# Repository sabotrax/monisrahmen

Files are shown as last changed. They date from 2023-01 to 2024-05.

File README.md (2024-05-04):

# monisrahmen

A digital picture frame you can send emails to.

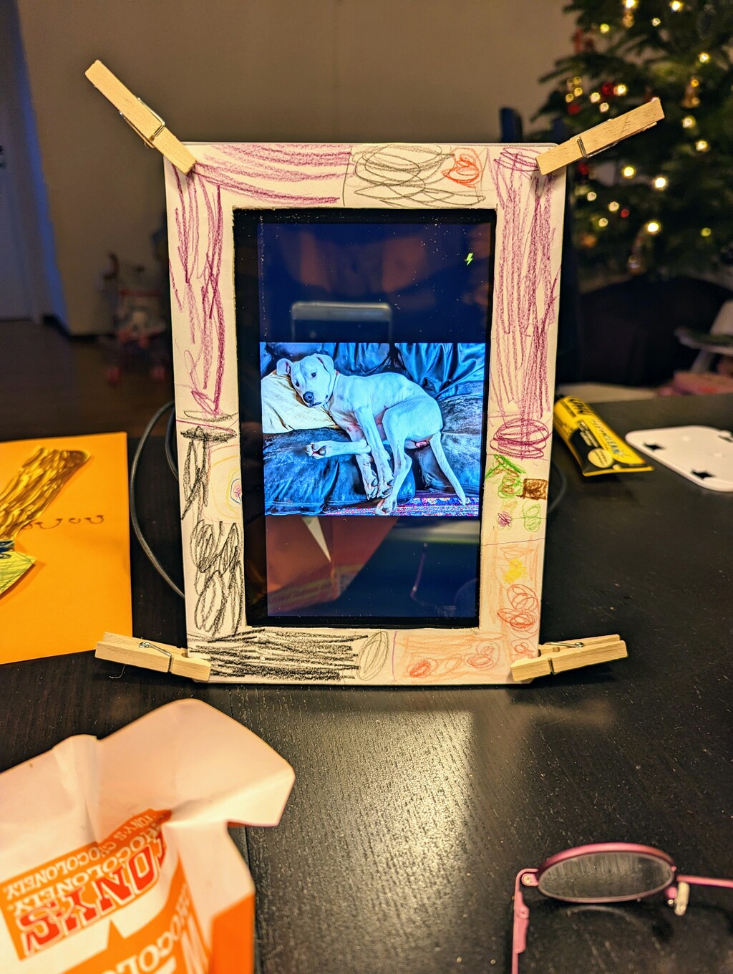
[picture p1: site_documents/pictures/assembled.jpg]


## Description

Send pictures as email attachments or put them on a network share.
They will be displayed in a random loop. 

The frame is 3D printed.  
Some light soldering may be required.

## Features

* Send one or more pictures as email attachments.
* Add more pictures by putting them on a network share.
* Duplicate files and non-image formats will be ignored.
* Screen blanking is controlled by a motion sensor.
* Off-hours can be enabled, so the screen stays off after blanking.
* A splash screen is showing device information.
* Most options are configurable.

### Remark

There's a redesigned version of the frame.  
Files with the naming scheme *frame2_* are referring to it.  
They're located in [site_documents/](site_documents/).  
A larger printer is required also.  
The software installation largely stays the same.

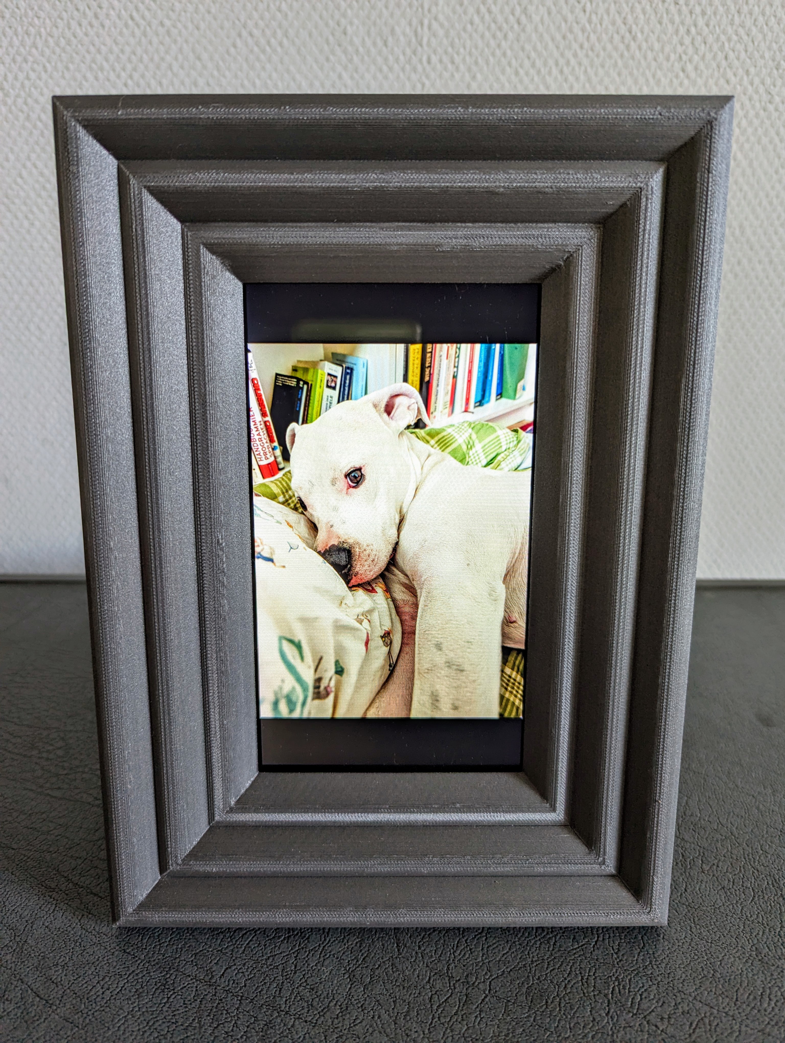
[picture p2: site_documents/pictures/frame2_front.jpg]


### Bill of materials

* 1 Raspberry Pi 2  
  The Raspberry 2 is sufficient for this project and can be found for relatively cheap in late 2022.
* 1 USB WLAN adapter like Edimax or TP-Link brand
* 1 WaveShare model 7" IPS/QLED Integrated Display, 1024x600, 70H-1024600
* 1 RCWL-0516 doppler radar microwave motion sensor module
* 1 HDMI cable of 30 cm length
* 8 M2.5 screws, nuts and standoffs  
  Plastic is fine.
* 1 USB-A to Micro USB-B cable
* 1 USB-A to USB-C cable
* 1 USB wall charger  
  The power draw of the display is about 350 mA. 100 mA when blanked.
* 6 square head female-to-female DuPont cables
* 1 4x1 male pin-headers
* Small cable ties

### Tools

* Soldering equipment
* Hot glue gun

### 3D printing

The STL files are located in ``site_documents/designs/``.  
Frame and stand have been printed in PETG with 15 % infill and supports, but PLA will also work.

### Hardware setup

* See [ASSEMBLY](site_documents/ASSEMBLY.md).

### Installing

* Install Pi OS Lite 32-bit using the Raspberry Pi Imager.  
  You can set up the host name, user account, SSH and Wifi in the options of the Imager.
  You should then be able to ssh into your Raspberry.

* Install dependencies:
    ```
    sudo apt-get install fbi fonts-dejavu-core git incron python3 python3-pip python3-venv samba
    ```

    If using DietPi instead of Pi OS add also:
    ```
    sudo apt-get install libopenjp2-7 libxcb1
    ```

* Download the software:
    ```
    git clone https://github.com/sabotrax/monisrahmen.git
    ```

* Create the virtual environment for Python and install the required modules:
    ```
    cd monisrahmen
    python3 -m venv .
    source bin/activate
    pip3 install -r requirements.txt
    echo "source ~/monisrahmen/bin/activate" >> ~/.bashrc
    ```

* Create ``.env`` as the configuration file:
    ```
    # installation directory
    PROJECT_PATH=/home/schommer/monisrahmen
    # email account settings
    EMAIL_USER=IMAP_USER
    EMAIL_PASS=IMAP_PASSWORD
    EMAIL_HOST=IMAP_HOST
    EMAIL_PORT=993
    EMAIL_INBOX=Inbox
    # email subject for image processing
    EMAIL_KEYWORD=foto
    # number of emails to fetch
    FETCH_EMAIL=5
    # delete emails after retrieval
    DELETE_EMAIL=False
    # unkown sender
    UNKNOWN_SENDER=Unknown
    # image reload time (seconds)
    RELOAD_IMAGE=120
    # image transition time (milliseconds)
    BLEND_IMAGE=500
    # motion sensor (either or)
    MOTION_SENSOR=RCWL-0516
    #MOTION_SENSOR=HLK-LD2410C # redesigned version
    # motion sensor timeout for screen blanking (seconds)
    DISPLAY_TIMEOUT=120
    # display off-hours
    # the screen stays off after blanking during this period
    # leave empty if not using
    START_DISPLAY_OFF=23:00
    END_DISPLAY_OFF=07:00
    # monitoring is not implemented yet
    # leave empty if not using
    START_MONITORING=
    END_MONITORING=
    # network device
    NETWORK_DEVICE=wlan0
    # network error message
    NETWORK_ERROR="Network error!"
    # splash image font
    FONT_SIZE=30
    # screen resolution
    SCREEN_WIDTH=1024
    SCREEN_HEIGHT=600
    # be verbose
    DEBUG=False
    ```

* Configure the display in ``/boot/config.txt``.  
    For the WaveShare model 7" IPS/QLED 1024x600 70H-1024600:
    ```
    hdmi_group=2
    hdmi_mode=87
    hdmi_cvt=1024 600 60 6 0 0 0
    hdmi_drive=1
    ```

    Display blanking:
    ```
    #dtoverlay=vc4-kms-v3d
    hdmi_blanking=1
    ```
    Blanking an HDMI display would work only on the Pi 2 if we used the legacy graphics driver.

    Rotate the virtual console:
    ```
    display_hdmi_rotate=3
    ```
    This would also only work with the legacy driver.

* Suppress boot messages.  
    Append to the end of the line of ``/boot/cmdline.txt``:
    ```
    consoleblank=1 logo.nologo vt.global_cursor_default=0
    ```

    Add to ``/boot/config.txt``:
    ```
    avoid_warnings=1
    disable_splash=1
    ```

* Configure the Samba share.  
    Add to the end of ``/etc/samba/smb.conf``:
    ```
    [bilder]
    # change accordingly to your installation directory
    path = /home/schommer/monisrahmen/pictures/
    public = yes
    writable = yes
    comment = Bilder
    printable = no
    guest ok = yes
    ```

    Change directory rights so image files can be managed from your file manager:
    ```
    chmod 777 pictures/
    ```

* Edit the shell scripts.  
    Change the installation directories in ``sitebin/restart_fbi.sh`` and ``sitebin/startup.sh``.  
    You can now test the scripts by setting ``DEBUG=True`` in ``.env``,  
    then send an image to the email address using the keyword as the subject and  
    ```
    ./get_pics_by_mail.py
    ```
    You should find the image file in pictures/.  
    Next, add another image to the Samba share and
    ```
    ./sync_database.py
    ```
    If you ``cat user_data/db.json``, there should be two entries in the database.

* Set up Cron.  
    For your user ``crontab -e``:
    ```
    INST_DIR=/home/schommer/monisrahmen
    VENV_PYTHON=/home/schommer/monisrahmen/bin/python3
    @reboot                $VENV_PYTHON $INST_DIR/blank_screen.py
    0,15,30,45 * * * *     $VENV_PYTHON $INST_DIR/get_pics_by_mail.py
    @hourly                $VENV_PYTHON $INST_DIR/sync_database.py
    ```

    For root ``sudo crontab -e``:
    ```
    INST_DIR=/home/schommer/monisrahmen
    @reboot                $INST_DIR/sitebin/startup.sh > /dev/null 2>&1
    ```

    Adjust INST_DIR according to your installation directory.  

* Set up incron.  
    Add root to ``/etc/incron.allow``:
    ```
    echo root > /etc/incron.allow
    ```

    For root ``sudo incrontab -e``:
    ```
    /home/schommer/monisrahmen/site_run     IN_CREATE       /home/schommer/monisrahmen/sitebin/restart_fbi.sh
    ```

    Adjust the directories in the incrontab file accordingly.  
    fbi is restarted by incron after a new image attachment has been downloaded and processed.

* Optimize the system.  
    Disable logging in ``/etc/systemd/journald.conf``:
    ```
    Storage=none
    ```

    Disable unnecessary services:
    ```
    systemctl disable avahi-daemon
    systemctl stop avahi-daemon
    systemctl disable triggerhappy
    systemctl stop triggerhappy
    ```

## License

Distributed under the New BSD License, see LICENSE.txt.

## Acknowledgments

Inspiration, documentation, code snippets, etc.
* [Building a living photo frame](https://www.ofbrooklyn.com/2014/01/2/building-photo-frame-raspberry-pi-motion-detector/)
* Waveshare display [Wiki](https://www.waveshare.com/wiki/70H-1024600) 
* [RCWL-0516](https://github.com/jdesbonnet/RCWL-0516) microwave radar motion detector
* Raspberry Pi [config.txt](https://www.raspberrypi.com/documentation/computers/config_txt.html) documentation
* Crontab configuration ``man 5 crontab``
* incrontab configuraiton ``man 5 incrontab``
* Samba configuration ``man 5 smb.conf``
* fbi - Linux framebuffer image viewer ``man fbi``

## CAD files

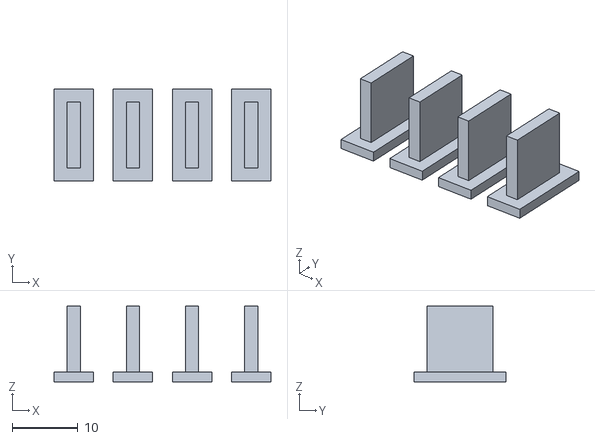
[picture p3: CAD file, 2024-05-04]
site_documents/designs/frame2_passepartout_pin.stl
33.0 x 14.0 x 11.5

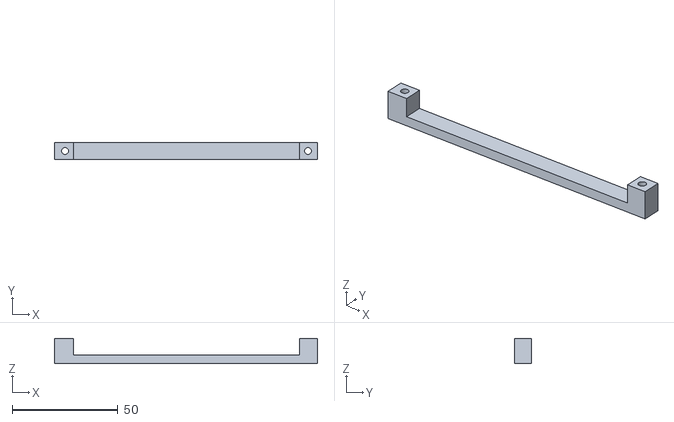
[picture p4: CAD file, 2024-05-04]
site_documents/designs/frame2_upper_bracket.stl
124.5 x 8.00 x 12.0

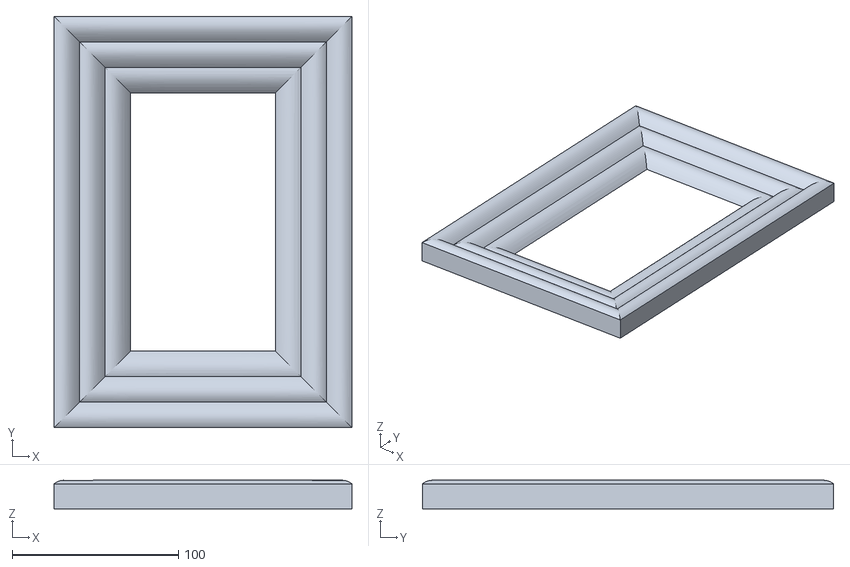
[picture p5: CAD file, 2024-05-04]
site_documents/designs/frame2_passepartout.stl
179.0 x 247.0 x 17.1

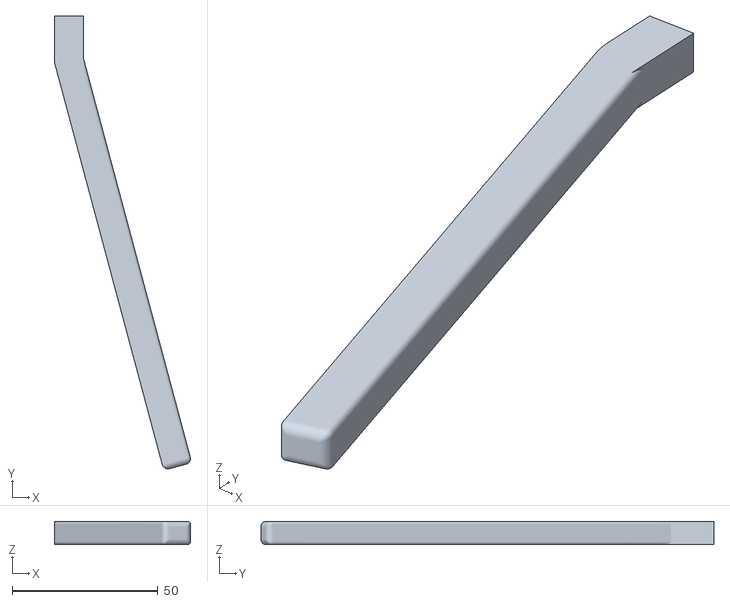
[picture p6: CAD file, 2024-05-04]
site_documents/designs/frame2_stand.stl
46.7 x 155.6 x 8.00

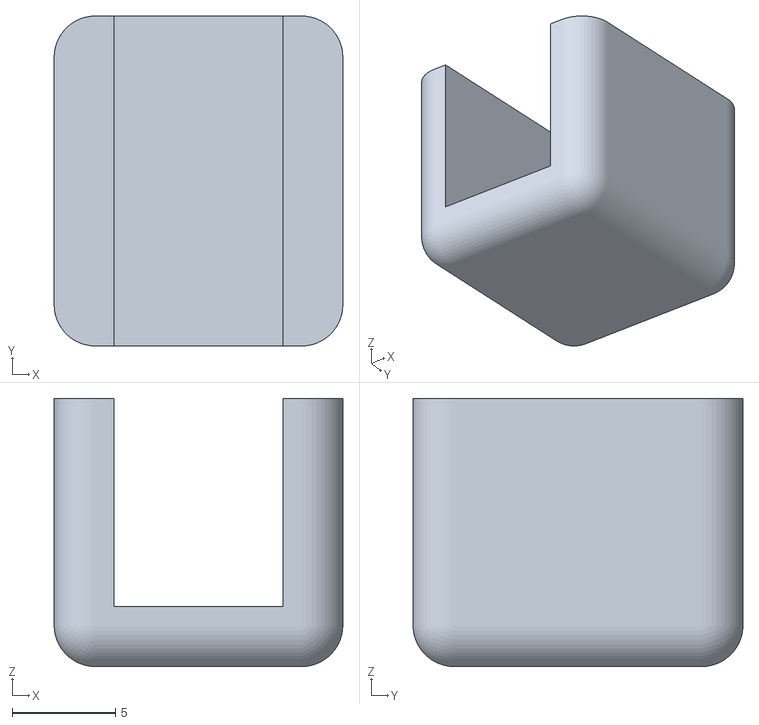
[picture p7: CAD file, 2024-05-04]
site_documents/designs/frame2_stand_mount.stl
14.0 x 16.0 x 13.0

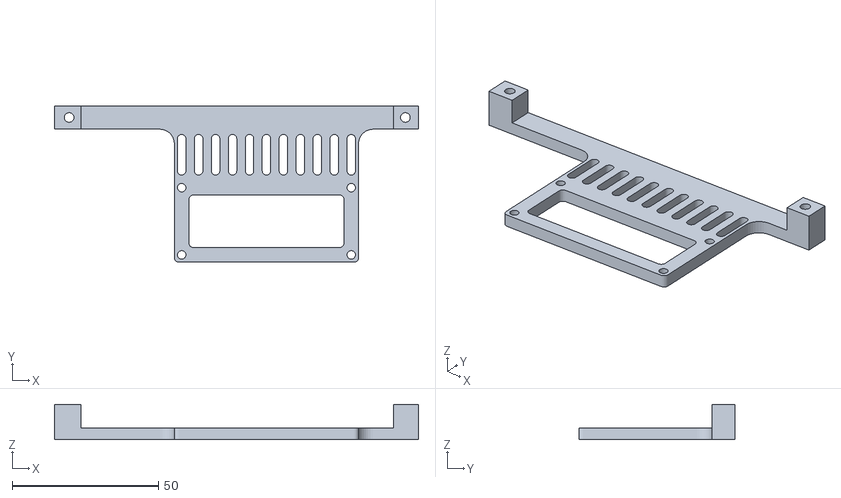
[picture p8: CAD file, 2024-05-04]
site_documents/designs/frame2_lower_bracket_pi_mount.stl
124.5 x 53.5 x 12.0

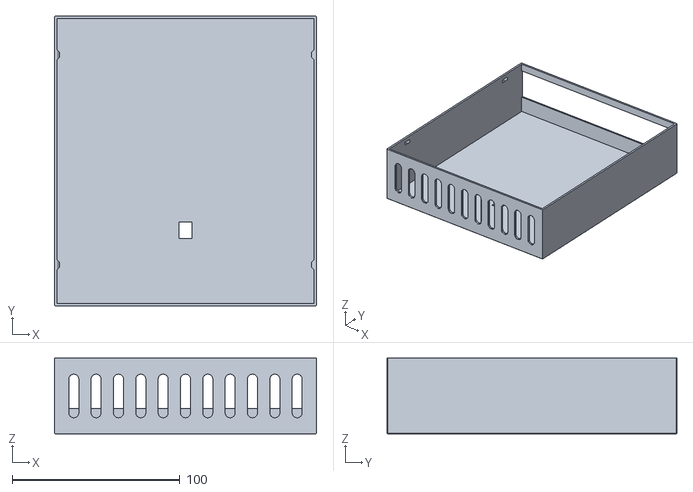
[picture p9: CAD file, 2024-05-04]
site_documents/designs/frame2_case.stl
156.0 x 172.5 x 45.0

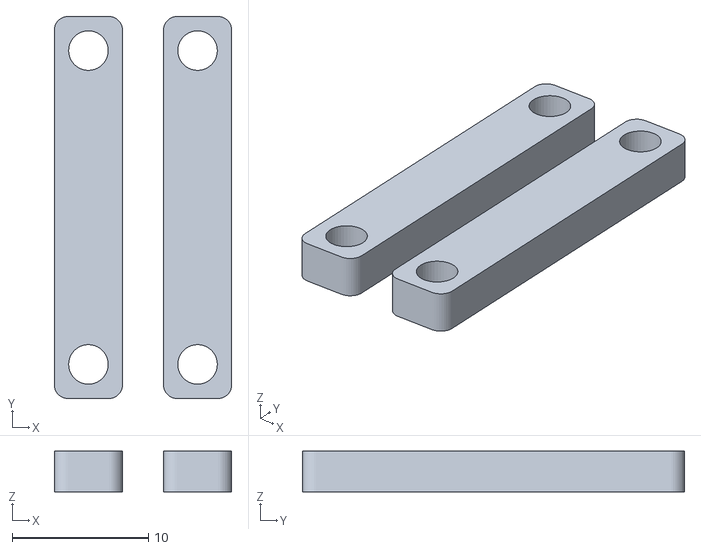
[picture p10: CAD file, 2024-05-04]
site_documents/designs/frame2_pi_spacer.stl
13.0 x 28.0 x 3.00

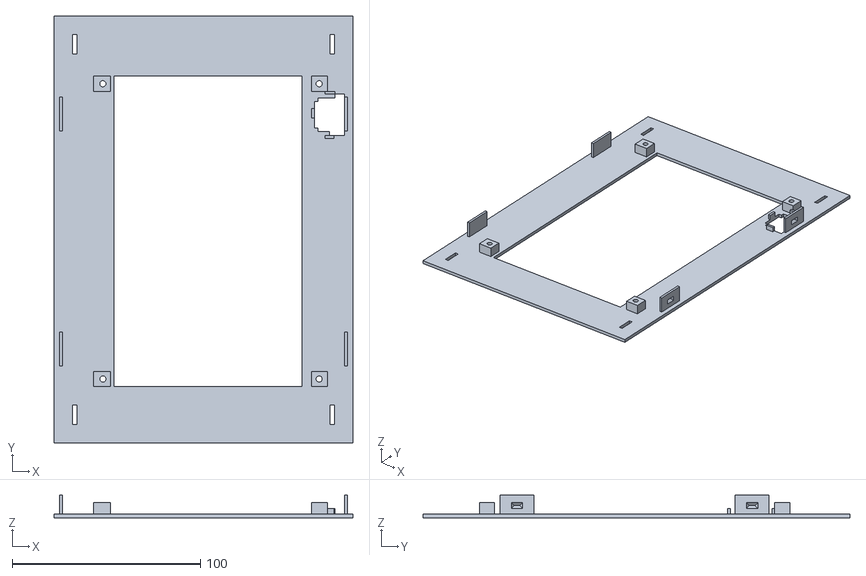
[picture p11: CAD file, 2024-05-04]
site_documents/designs/frame2_base.stl
159.0 x 227.0 x 12.0

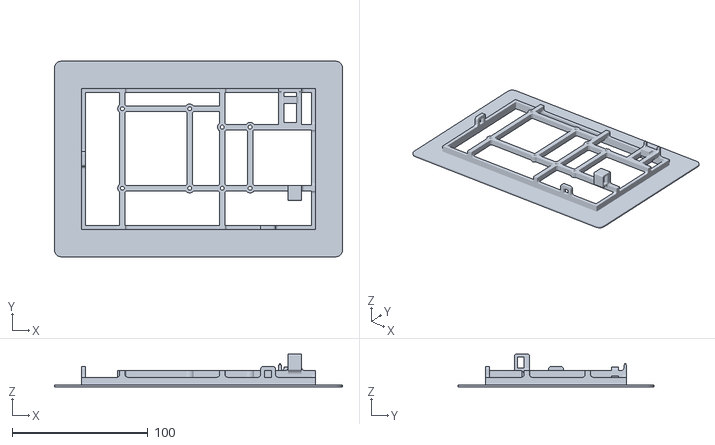
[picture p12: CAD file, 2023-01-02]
site_documents/designs/mr_frame.stl
212.0 x 144.0 x 24.0

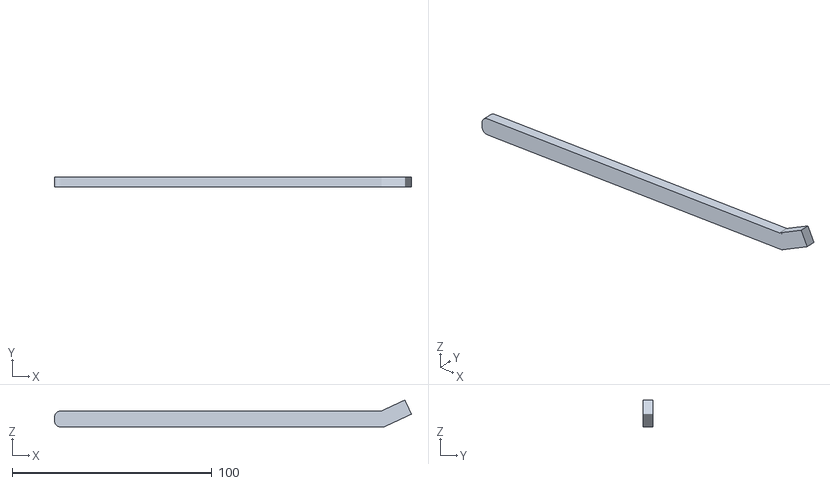
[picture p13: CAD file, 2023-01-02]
site_documents/designs/mr_stand.stl
178.6 x 5.00 x 13.5

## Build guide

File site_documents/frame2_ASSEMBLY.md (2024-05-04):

## Assembly instructions

### Overview

These instructions are for the redesigned frame.

### BOM:

* Printed parts.
* 4 x M3*18 screw and nut.
* 4 x M25*12 screw and nut.
* 3 x Jumper wire female-to-female 20 cm.
* 1 x HDMI cable mini HDMI male to HDMI male 30 cm.
* 1 x USB cable micro male to micro male.
* 1 x USB cable A to micro male.
* 1 x Display Waveshare 7inch QLED 1024×600 (Touch is not used atm, so this is a waste of money. Go for the non-touch version if available.)
* 1 x Raspberry Pi Zero 2.
* 1 x Sensor HLK-LD2410C Human Presence Motion Module.

### Step 1

* Use pictures/frame2_board.jpg as a reference.
* Mount the Pi Zero to the lower bracket using 4 x M25 screws fitting the spacers between Pi and bracket.

### Step 2

* Insert 4 x M3 screws into the base from underneath.
* Mount the display onto the base via the screws with the HDMI port facing down and away from the sensor mount.

### Step 3

* Mount the lower and upper brackets onto the base and fix them with 4 x M3 nuts.

### Step 4

* Connect 3 jumper wires to the pins of the sensor VCC, GND and OUT.
* Connect the wires to the Pi VCC to Pin 2 (5V), GND to Pin 6 (GND) and OUT to Pin 11 (GPIO17).
* Secure the sensor to the base with a drop of super glue (optional).

### Step 5

* Use frame2_back.jpg as a reference. 
* Glue the mount of the stand to the case so that it sits above the opening in the back.

### Step 6

* Clip the case onto the snap fits of the base with the groves in the case facing up.
* Connect the display to the Pi using the USB and HDMI cables fitting the cables through the culvert of the case. Use the non-touch micro USB port of the display.
* Connect the USB A cable to the remaining micro USB port of the Pi to power the frame.

### Step 7

* Put the base on the passepartout and fix it with the retaining pins. You might have to sand down the pins somewhat.
* Fit the stand into the mount on the back of the case. You might have to sand down the insert part of the stand somewhat.

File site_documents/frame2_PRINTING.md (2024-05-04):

## 3D printing instructions

### Overview

These instructions are for the redesigned frame.

All parts can be printed in PLA with default infill (15% grid in OrcaSlicer for example).

#### With support

* base, lower_bracket_pi_mount, upper_bracket.
* case: add/paint additional manual support under the wide bridge (upper of the culvert).

#### Without support

* passepartout, passpartout_pins, pi_spacer, stand, stand_mount.

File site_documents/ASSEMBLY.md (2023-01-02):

## Assembly instructions

### Overview

Parts of the mounting frame:
* The base plate for the sensor board in the top left.
* The slot for the frame stand in the top right.
* The mounting holes for the daughter board of the display in the upper mid.
* The mounting holes for the Raspberry Pi in the lower half.
* Two strain reliefs in the upper right and bottom mid.

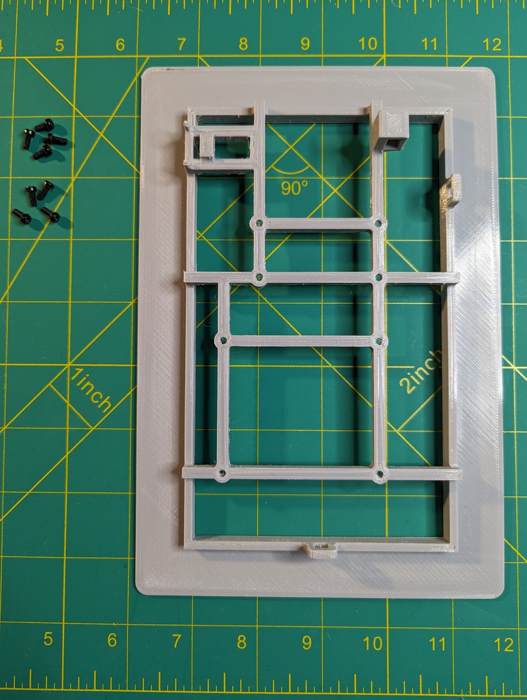
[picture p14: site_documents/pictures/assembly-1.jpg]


### Step 1

Push 8 M2.5 screws through the mounting holes from the bottom side up.

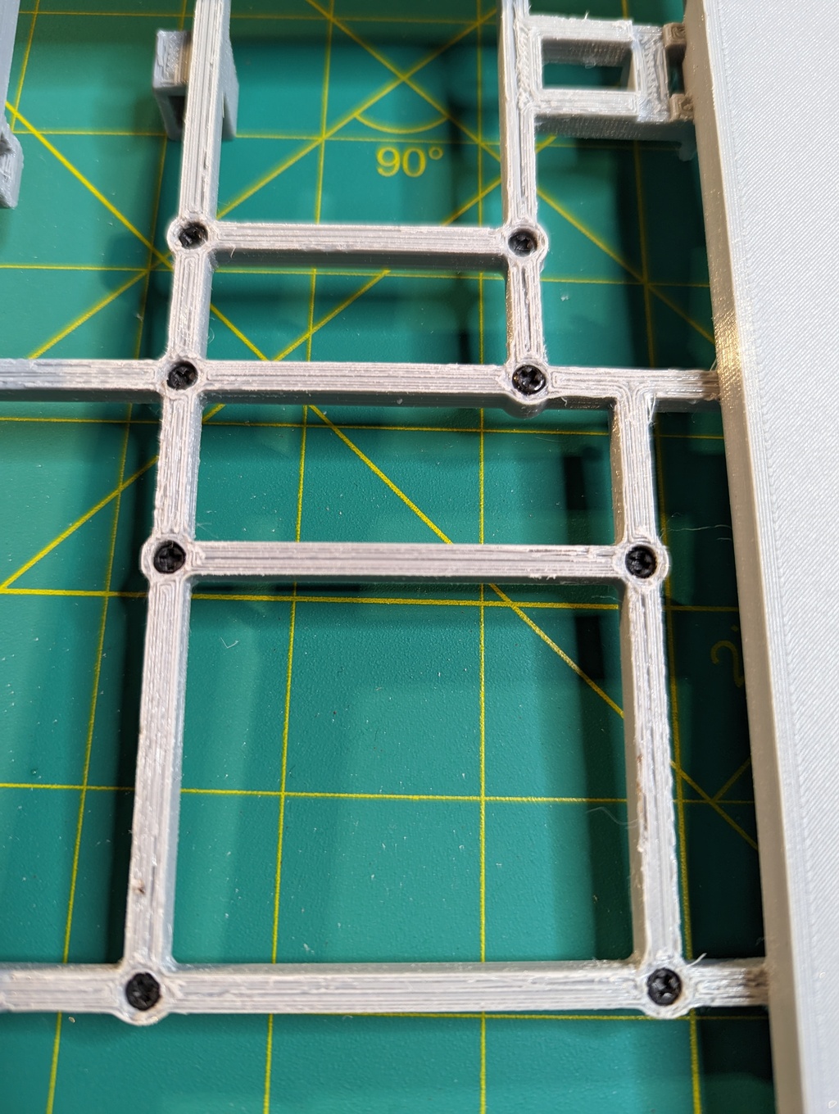
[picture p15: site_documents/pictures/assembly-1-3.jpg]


The outcome should look like this:

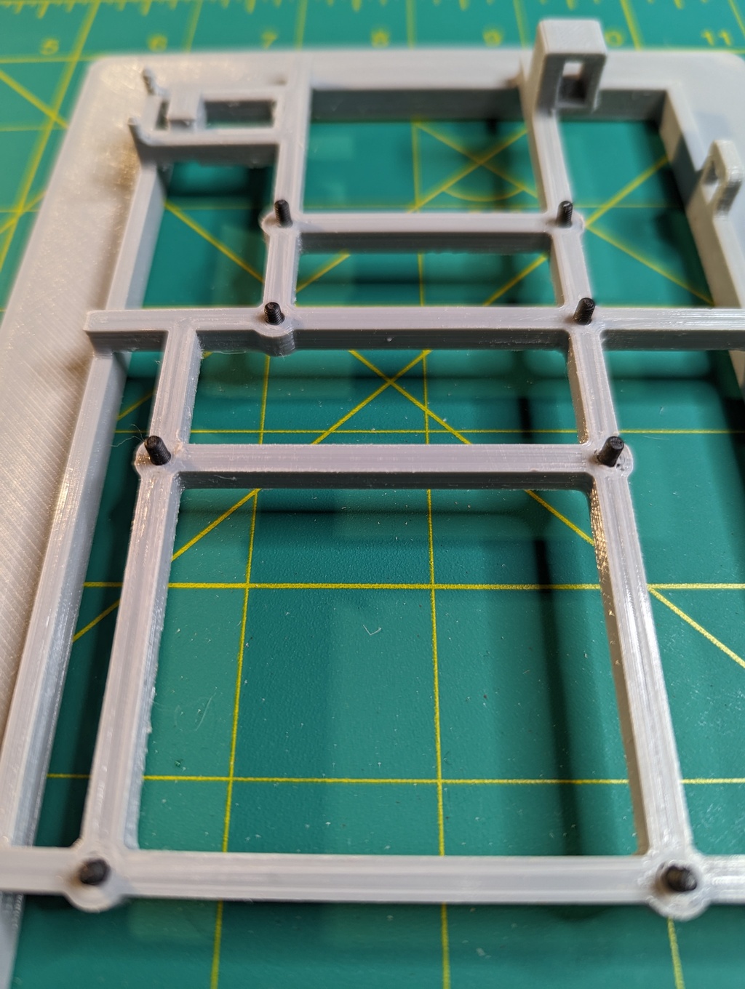
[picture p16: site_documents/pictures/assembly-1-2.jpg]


### Step 2

Screw 8 M2.5 standoffs onto the screws.

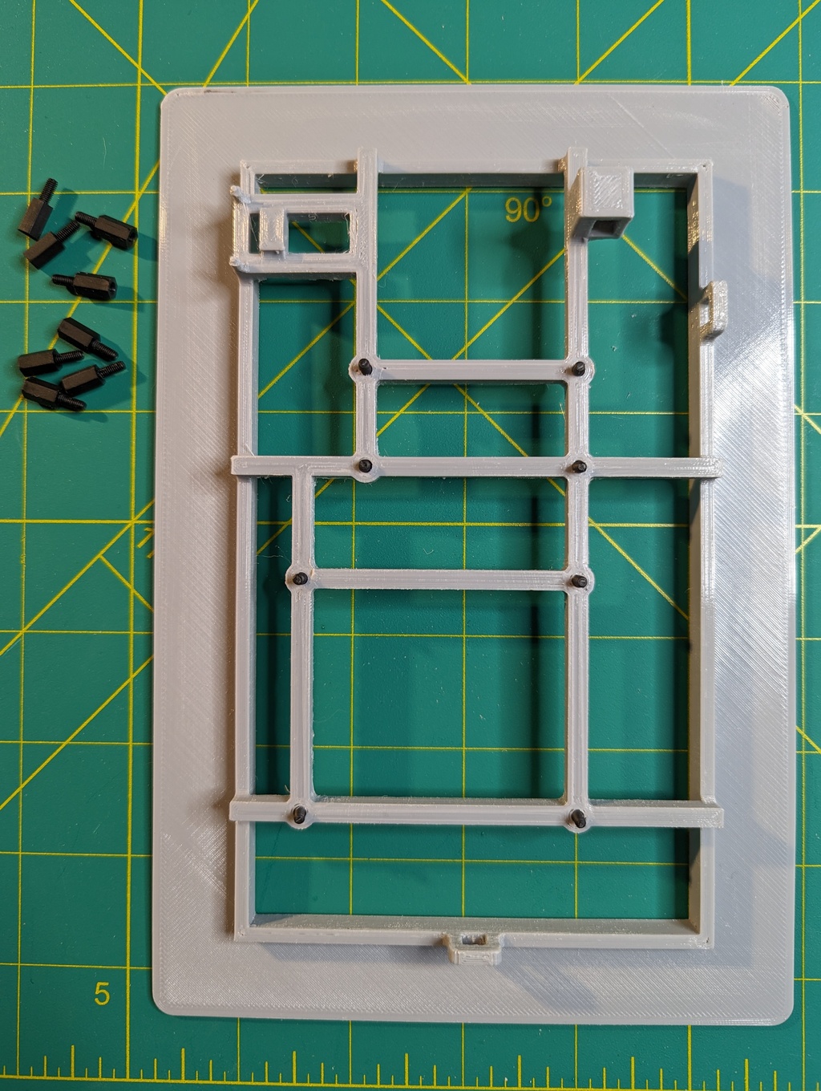
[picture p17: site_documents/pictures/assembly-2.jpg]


The outcome should look like this:

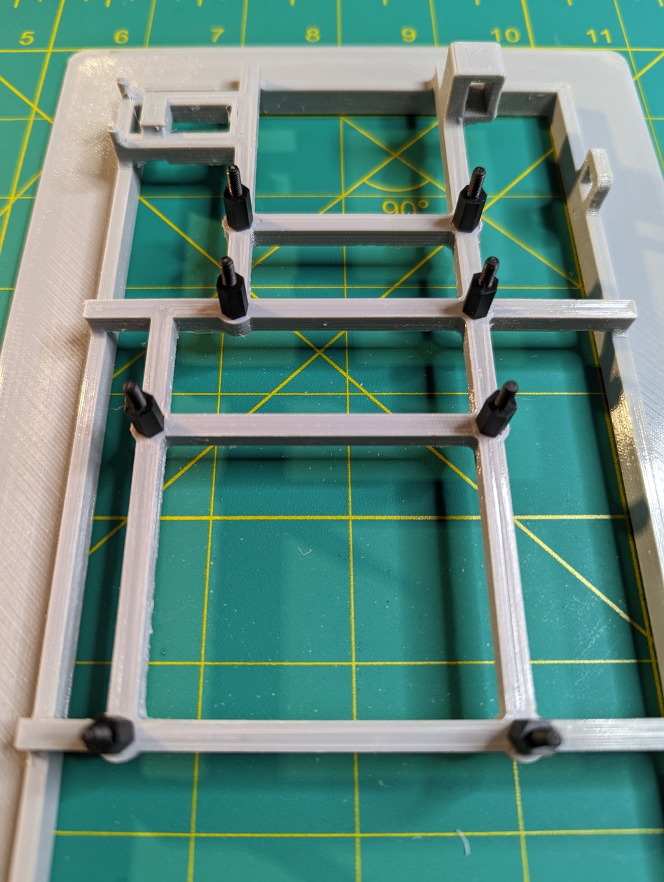
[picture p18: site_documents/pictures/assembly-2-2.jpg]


### Step 3

Solder the 4x1 pin-header to the back side of the sensor board.  
The sensor's actual antenna is facing down.

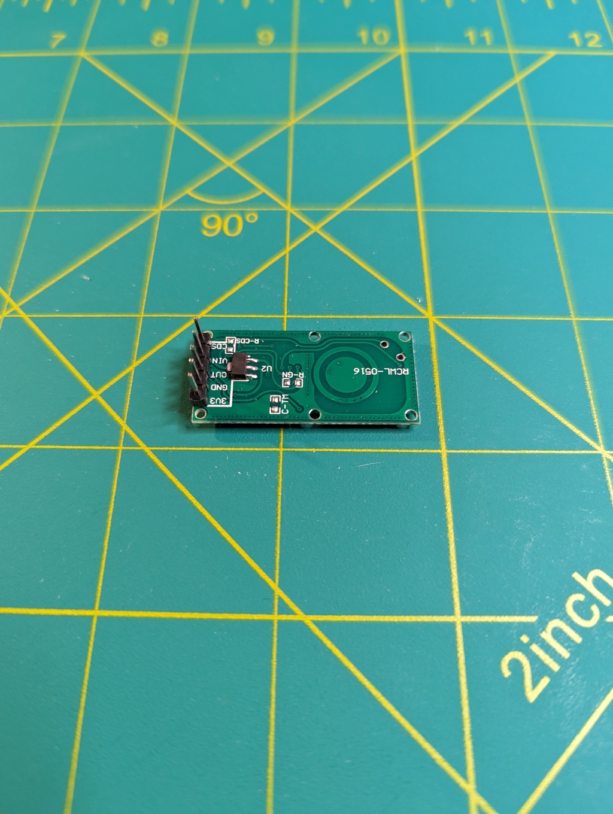
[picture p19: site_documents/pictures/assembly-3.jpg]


### Step 4

Connect the boards (board pin numbering, not BCM) using 6 DuPont cables.
* Raspberry Pi to radar sensor board:  
  2 - VIN  
  6 - GND  
  11 - OUT  
  13 - CDS  
* Raspberry Pi to HDMI board:   
  12 - PWM  
  14 - GND  

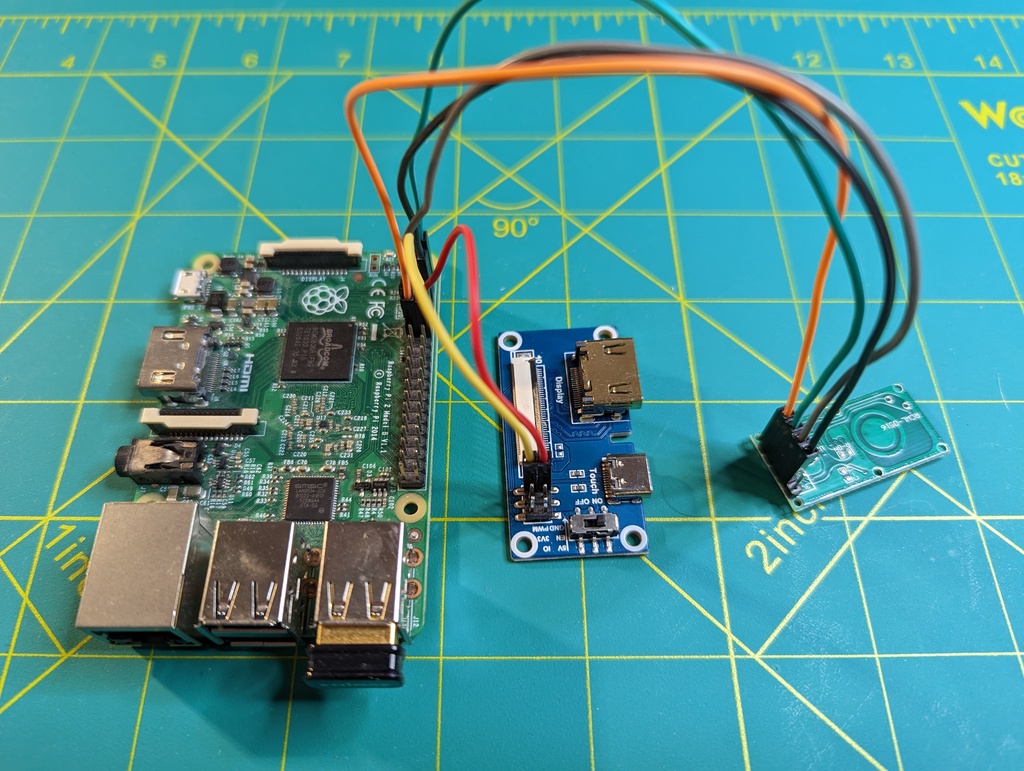
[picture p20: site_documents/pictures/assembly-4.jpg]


Mount the Raspberry Pi and sensor board onto the standoffs and tighten them down with 8 M2.5 nuts.

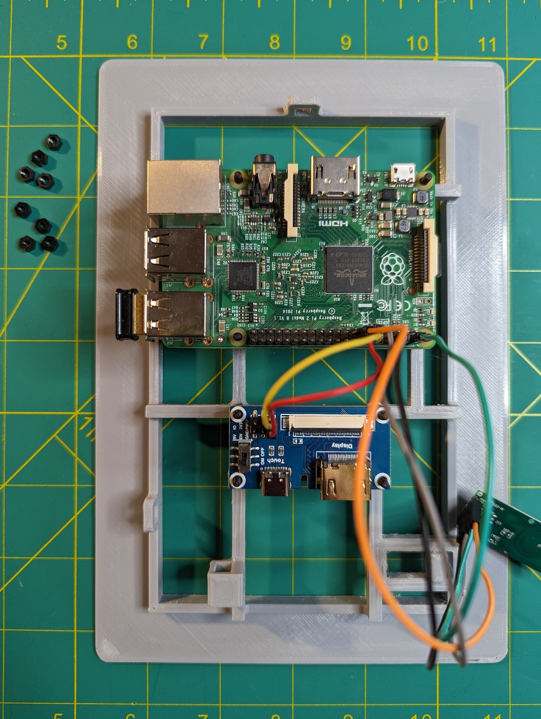
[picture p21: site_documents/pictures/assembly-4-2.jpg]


The outcome should look like this:

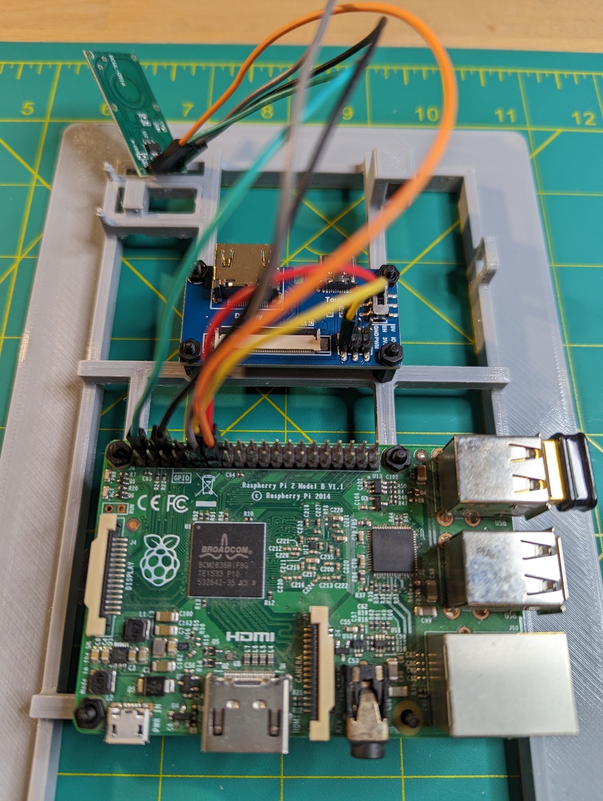
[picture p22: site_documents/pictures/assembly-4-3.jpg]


### Step 5

Place the sensor board onto the two tiny standoffs of the frame using the central mounting holes.  
Tie the board to the base plate using a cable tie. There's a gap for the tie on the underside of the frame.

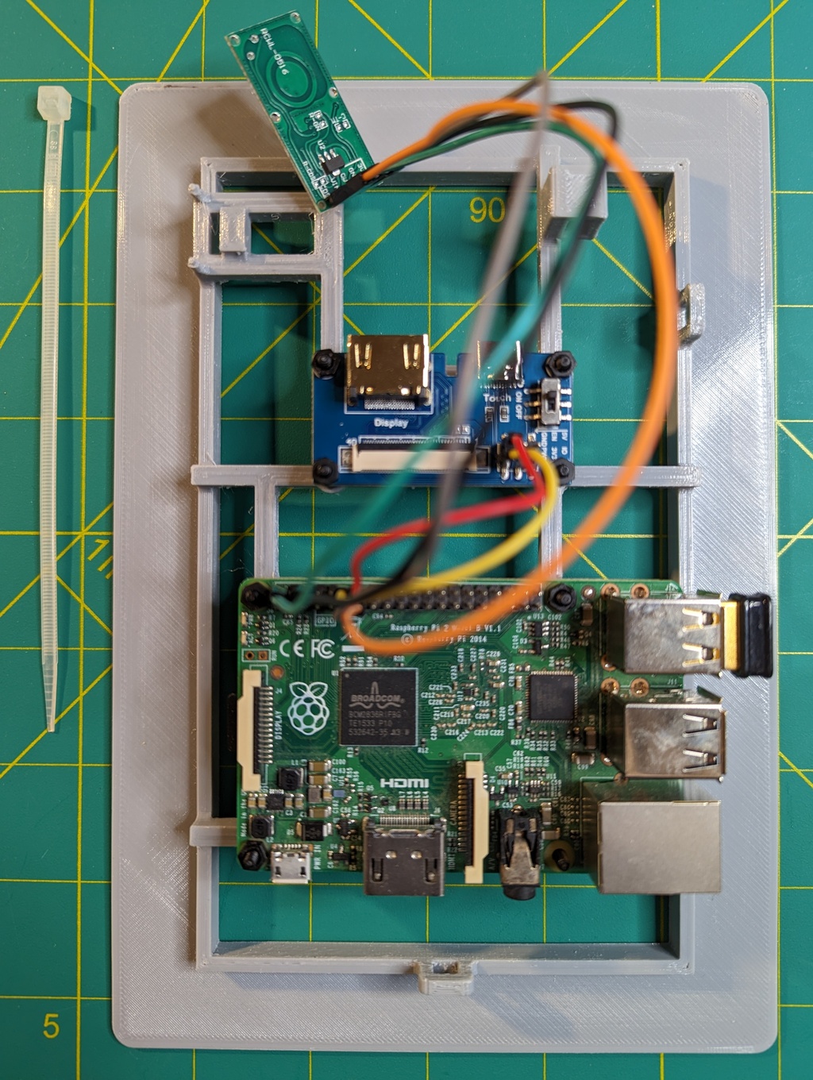
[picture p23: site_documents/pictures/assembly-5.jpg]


The outcome should look like this:

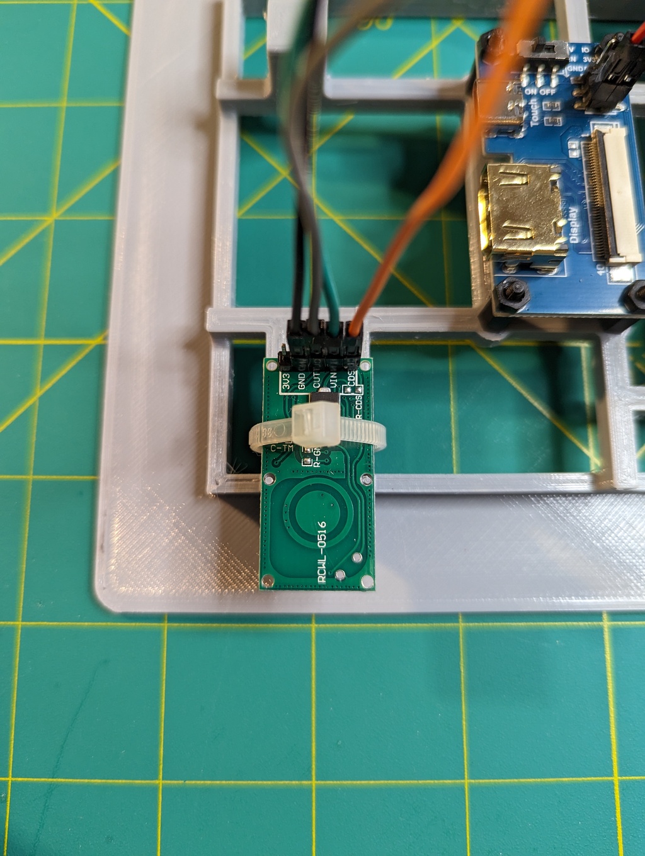
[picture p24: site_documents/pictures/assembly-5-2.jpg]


### Step 6

Connect the HDMI ports of the Raspberry Pi and the daughter board of the display with the HDMI cable.

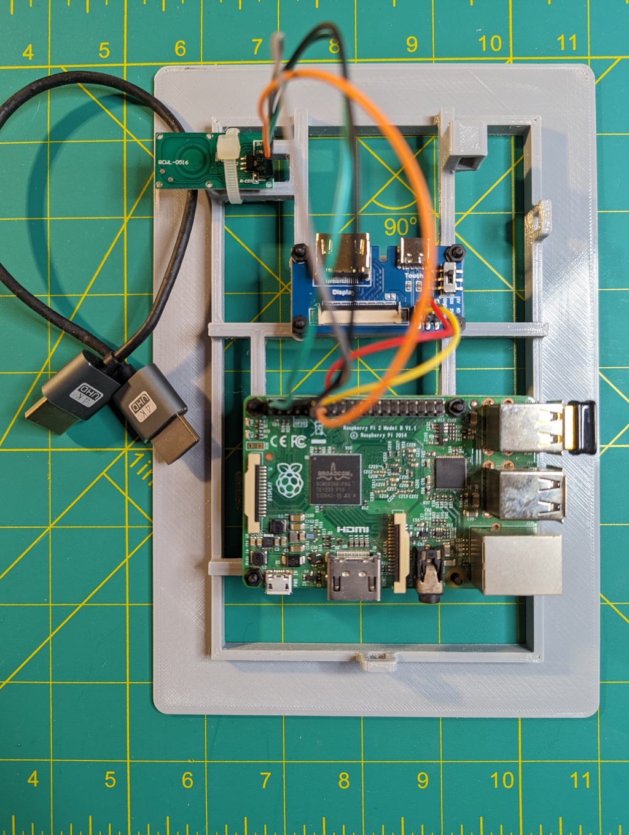
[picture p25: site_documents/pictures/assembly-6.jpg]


The outcome should look like this:

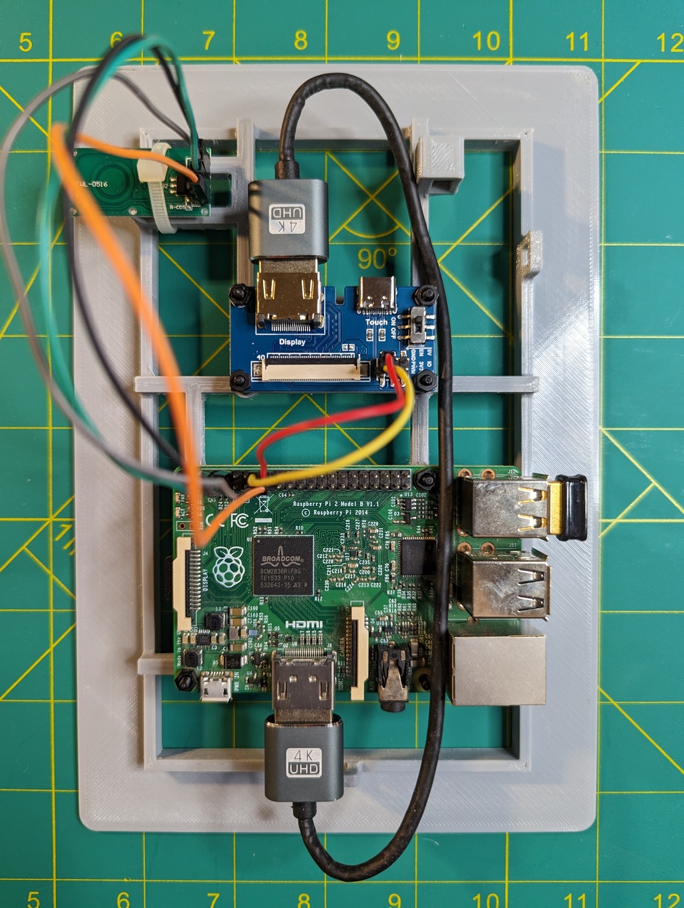
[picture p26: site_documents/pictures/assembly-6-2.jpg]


### Step 7

Using the USB cable, connect the USB-C port of the HDMI board to a USB-A port of the Raspberry Pi.  
Secure it to the frame using the strain relief. You might want to use a shorter cable than I did.

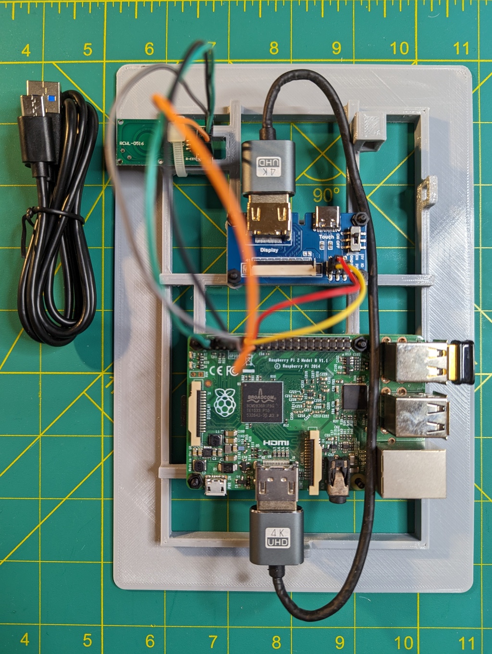
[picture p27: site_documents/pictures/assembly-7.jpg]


The outcome should look like this:

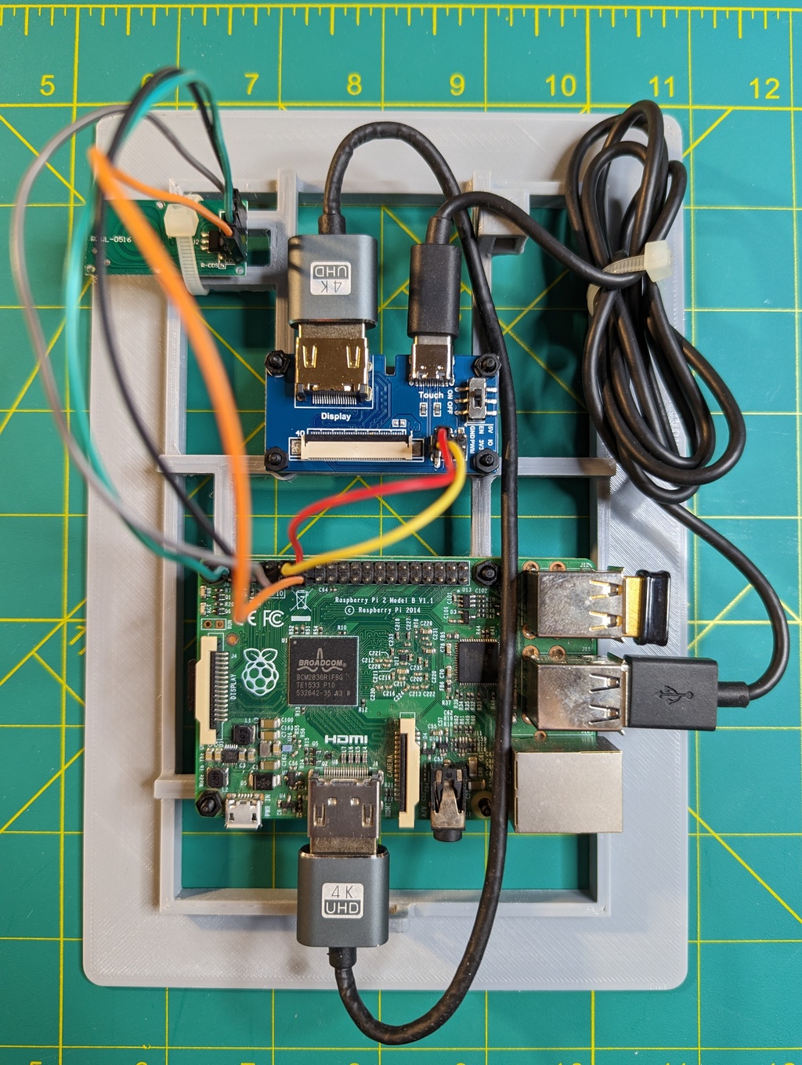
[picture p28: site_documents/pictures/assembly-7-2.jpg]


### Step 8

Connect the HDMI-FPC cable to the display with the lettering on the cable facing towards you.  
These cables are susceptible to breaking, so you might want to consider a tutorial on Youtube.

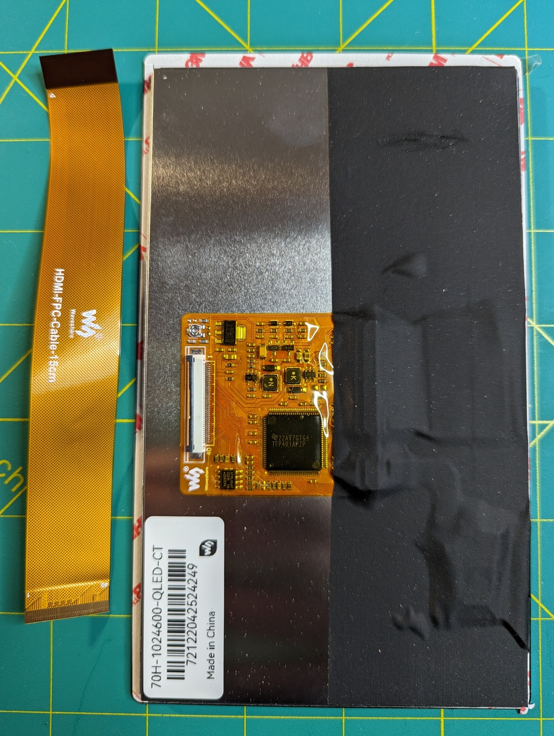
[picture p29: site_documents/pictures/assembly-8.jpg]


Put the frame over the display passing the FPC table up through the frame.

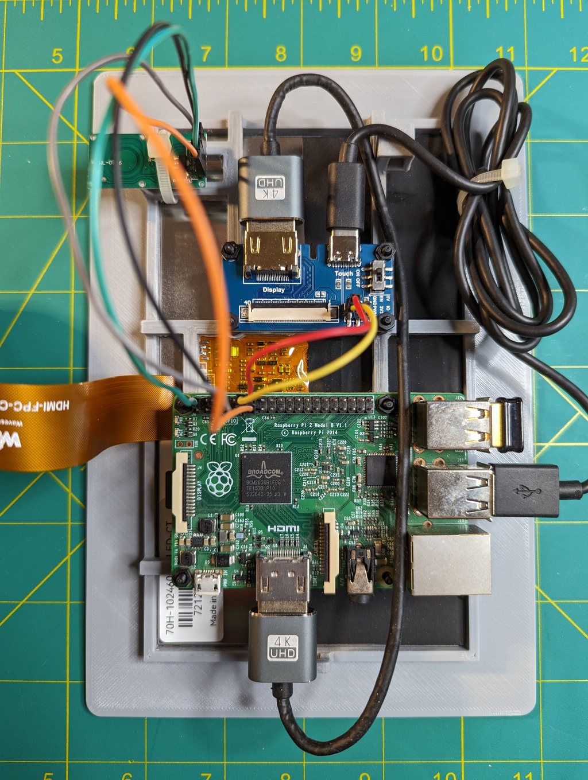
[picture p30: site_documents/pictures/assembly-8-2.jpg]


Connect the FPC cable to the HDMI board.

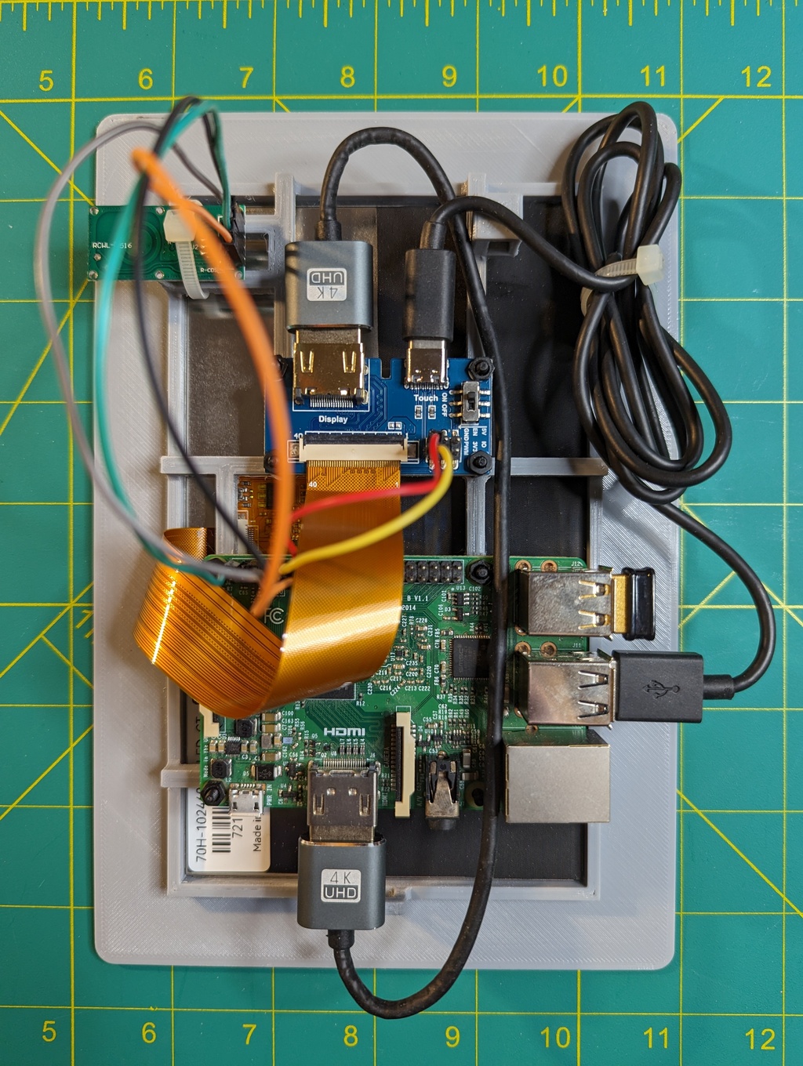
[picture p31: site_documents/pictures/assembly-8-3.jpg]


### Step 9

Connect the Micro-USB power cord to the Raspberry Pi and secure it to the strain relief using a cable tie.

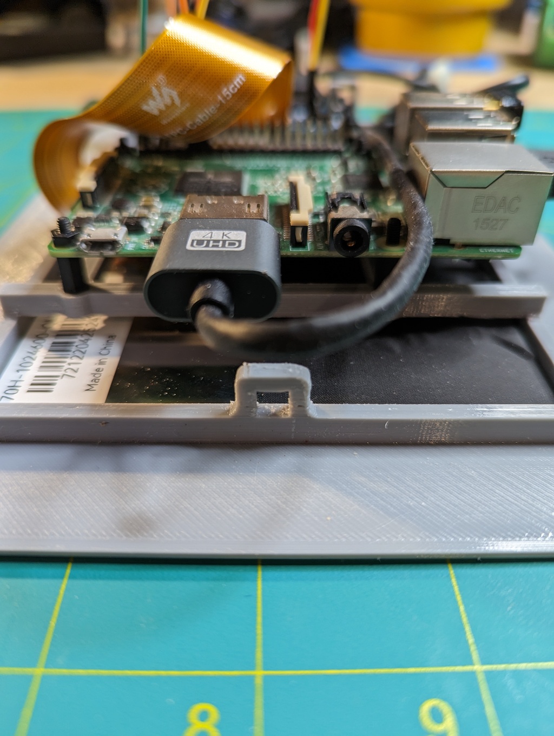
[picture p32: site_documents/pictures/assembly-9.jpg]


The outcome should look like this:

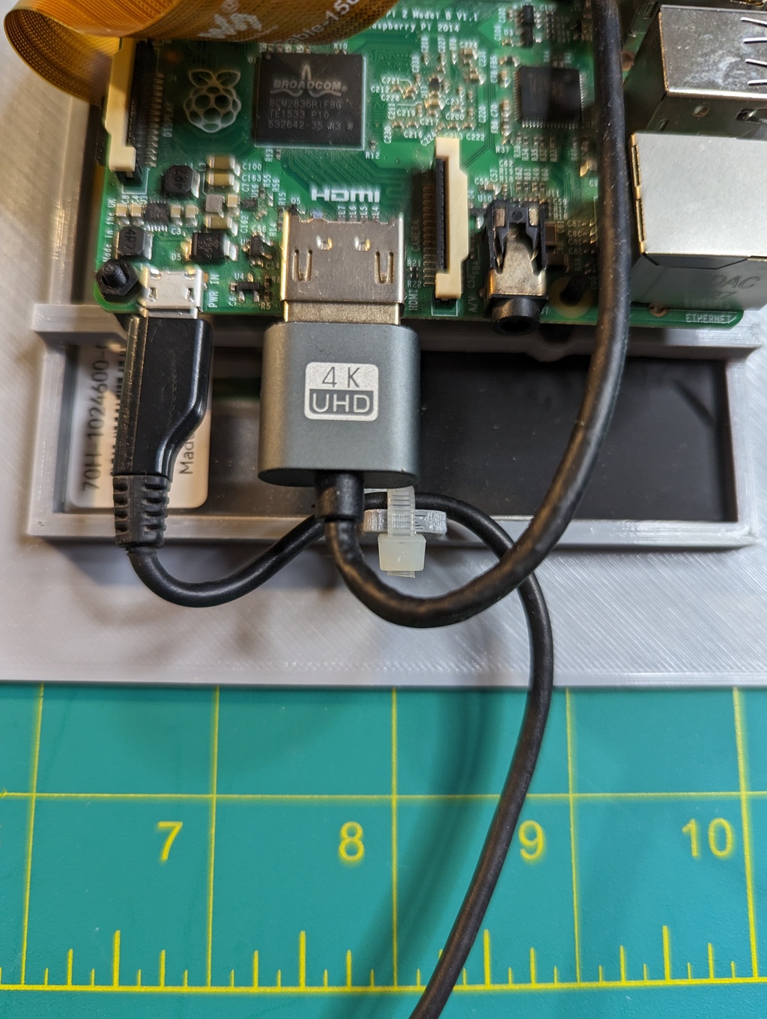
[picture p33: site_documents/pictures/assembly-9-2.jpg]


### Step 10

Sand down the skewed part of the frame stand so it can fit in the mounting slot.

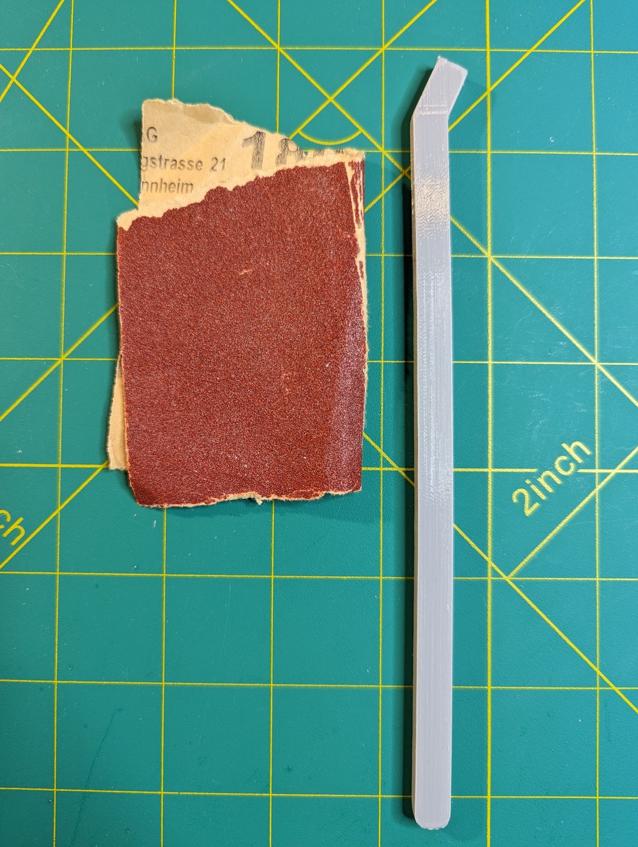
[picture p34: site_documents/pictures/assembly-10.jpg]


The outcome should look like this:

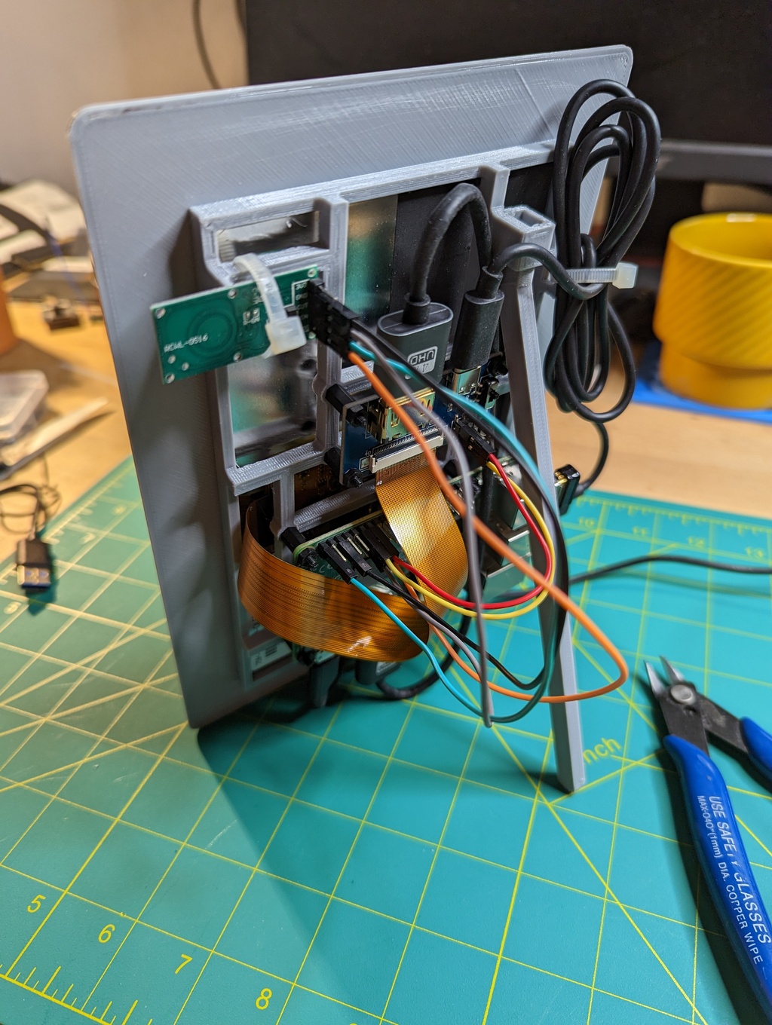
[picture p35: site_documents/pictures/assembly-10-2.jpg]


You can now go on with the software installation.

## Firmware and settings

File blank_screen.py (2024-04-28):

#!/usr/bin/env python3

# this script should be run by your user's crontab
# see README.md

import atexit
import RPi.GPIO as GPIO
import smtplib
import ssl
import subprocess
from datetime import datetime
from decouple import config
from email.message import EmailMessage
from helper import in_between_days
from time import sleep, time

DEBUG = config('DEBUG', default=False, cast=bool)
ms = config('MOTION_SENSOR')

GPIO.setmode(GPIO.BCM)

# Motion sensor
GPIO.setup(17, GPIO.IN)

if ms == "RCWL-0516":
    GPIO.setup(27, GPIO.OUT)
    # enable motion sensor
    GPIO.output(27, GPIO.HIGH)

# display brightness pwm
GPIO.setup(18, GPIO.OUT)
dim = GPIO.PWM(18, 1000)


@atexit.register
def goodbye():
    GPIO.cleanup()
    subprocess.run(["/usr/bin/vcgencmd", "display_power",
                    "1", "2"])


def motion_detect():
    motion = GPIO.input(17)
    return motion


def dim_display(mode):
    if mode == "off":
        dim.start(0)
        for duty in range(0, 101, 1):
            dim.ChangeDutyCycle(duty)
            sleep(0.01)
        sleep(0.5)
    else:
        dim.start(100)
        for duty in range(100, -1, -1):
            dim.ChangeDutyCycle(duty)
            sleep(0.01)
        sleep(0.5)


def send_mail():
    msg = EmailMessage()
    msg.set_content("The body of the email is here")
    msg["Subject"] = "An Email Alert"
    msg["From"] = "from@example.com"
    msg["To"] = "to@example.com"

    context = ssl.create_default_context()

    with smtplib.SMTP("mail.example.com", port=587) as smtp:
        smtp.starttls(context=context)
        smtp.login("from@example.com", "secretpassword")
        smtp.send_message(msg)


if __name__ == "__main__":
    blanked = False
    active = idle = time()
    send_alert = False
    i = 0
    while True:
        if motion_detect():
            if DEBUG:
                print("motion detected")
            i = 0
            active = time()
            if blanked:
                # only unblank the display when not during off-hours
                if not in_between_days(config('START_DISPLAY_OFF'),
                                       config('END_DISPLAY_OFF')):
                    subprocess.run(["/usr/bin/vcgencmd", "display_power",
                                    "1", "2"])
                    dim_display("on")
                    blanked = False
                    #now = datetime.now()
                    #if not send_alert and (start_monitoring <= now <=
                                        #end_monitoring):
                        #print("send mail")
                        #send_mail()
                        #send_alert = True
                elif DEBUG:
                    print("off-hours")
        else:
            if DEBUG:
                if blanked:
                    print("blanked")
                else:
                    print(f"wait for it: {i}/{config('DISPLAY_TIMEOUT')}")
                    i += 1
            idle = time()
            if not blanked and (idle - active > config('DISPLAY_TIMEOUT',
                                                       cast=int)):
                if DEBUG:
                    print("blank now")
                dim_display("off")
                subprocess.run(["/usr/bin/vcgencmd", "display_power",
                                "0", "2"])
                blanked = True
        sleep(1)

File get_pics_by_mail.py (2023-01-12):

#!/usr/bin/env python3

import email
import imaplib
import os
import random
import re
import string
from decouple import config
from email.header import decode_header
from helper import validate_picture, DuplicateImageExeption
from pathlib import Path
from PIL import UnidentifiedImageError
from time import time
from tinydb import TinyDB

DEBUG = config('DEBUG', default=False, cast=bool)

db = TinyDB(config('PROJECT_PATH') + '/user_data/db.json')

imap = imaplib.IMAP4_SSL(config('EMAIL_HOST'), config('EMAIL_PORT',
                                                      default=993, cast=int))
imap.login(config('EMAIL_USER'), config('EMAIL_PASS'))

imap.select(config('EMAIL_INBOX'))
type, data = imap.search(None, 'ALL')
if DEBUG:
    print("FETCH: ", type)
mail_ids = data[0]
id_list = mail_ids.split()
id_list.reverse()
image_added = False

for i, id in enumerate(id_list):
    if DEBUG:
        print("counter: ", i)
    if i == config('FETCH_EMAIL', cast=int):
        if DEBUG:
            print("bye!")
        break

    typ, data = imap.fetch(id, '(RFC822)')
    msg = email.message_from_bytes(data[0][1])

    # decode the email subject
    email_subject, encoding = decode_header(msg["Subject"])[0]
    if isinstance(email_subject, bytes):
        # if it's a bytes, decode to str
        email_subject = email_subject.decode(encoding or 'utf8')
    if DEBUG:
        print("Subject:", email_subject)
    # check the email subject for the keyword
    email_keyword = config('EMAIL_KEYWORD')
    if not re.search(rf'{email_keyword}', email_subject, re.IGNORECASE):
        if DEBUG:
            print("skip!")
        continue

    # decode email sender
    email_sender, encoding = decode_header(msg.get("From"))[0]
    if isinstance(email_sender, bytes):
        email_sender = email_sender.decode(encoding)
    if DEBUG:
        print("From:", email_sender)

    # converts byte literal to string removing b''
    raw_email = data[0][1]
    raw_email_string = raw_email.decode('utf-8')
    email_message = email.message_from_string(raw_email_string)

    # download attachments
    for part in email_message.walk():
        if part.get_content_maintype() == 'multipart':
            continue
        if part.get('Content-Disposition') is None:
            continue
        fileName = part.get_filename()
        if bool(fileName):
            raw = part.get_payload(decode=True)

            # create unique file name
            letters = string.ascii_lowercase
            rnd_str = ''.join(random.choice(letters) for i in range(7))
            fileName = f'{rnd_str}-{fileName}'
            if DEBUG:
                print("new file name: ", fileName)

            # save file (for now)
            picture_path = config('PROJECT_PATH') + '/pictures'
            filePath = os.path.join(picture_path, fileName)
            fp = open(filePath, 'wb')
            fp.write(part.get_payload(decode=True))
            fp.close()
            if DEBUG:
                print("attachment: ", filePath)

            try:
                # verify picture and check for duplicate
                hd = validate_picture(filePath)

                # write image properties to db
                db.insert({'filename': fileName, 'sender': email_sender,
                           'date': int(time()), 'checksum': hd})

                image_added = True

            except DuplicateImageExeption:
                if DEBUG:
                    print("duplicate --> skip!")
                os.remove(filePath)
                pass
            except UnidentifiedImageError:
                if DEBUG:
                    print("unkown file: ", fileName)
                os.remove(filePath)
                pass

    if config('DELETE_EMAIL', default=False, cast=bool):
        if DEBUG:
            print("deleted email: ", id)
        imap.store(id, "+FLAGS", "\\Deleted")

# trigger fbi restart
if image_added:
    Path(config('PROJECT_PATH') + '/site_run/image_added').touch(exist_ok=True)

imap.expunge()
imap.close()
imap.logout()

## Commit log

2022-12-24 - fetch mail, download and save attachment if keyword is present. - delete mail if attachment has been processed.
2022-12-24 - check if the attachment is an image after it's been downloaded, delete it if it's not.
2022-12-24 - rotate image because of the portrait orientation of the frame if the image is in actual portrait mode (y-size > x-size).
2022-12-25 - fixed image rotation and moved the code to process_image(). - made the name of the email inbox configurable in config.py. - added requirements.txt
    [get_pics_by_mail.py]
2023-01-01 - changed the check for duplicate pictures. until now get_pics_by_mail.py checked if the file name of the attachment was already existing and skipped the processing of the mail if it was. I thought t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
    [get_pics_by_mail.py]
2023-01-01 - added ASSEMBLY.md containing the instructions for the hardware setup.
2023-01-01 - extended ASSEMBLY.md.
2023-01-01 - fixed README.md. - extended ASSEMBLY.md.
2023-01-02 - finished ASSEMBLY.md.
2023-01-02 - added STL files and updated README accordingly.
    [mr_frame.stl, mr_stand.stl]
2023-01-03 - replaced config.py with .env for configuration options in get_pics_by_mail.py.
    [get_pics_by_mail.py]
2023-01-04 - replaced config.py with .env for configuration options in create_splash_image.py. - made network interface configurable.
    [create_splash_image.py]
2023-01-05 - replaced config.py with .env for configuration options in blank_screen.py. - added code to use the radar sensor for room monitoring.
    [blank_screen.py]
2023-01-10 - fixed a bug where a MIME encoded-word subject could not be decoded by imaplib. - cleaned up code.
    [get_pics_by_mail.py]
2023-01-11 - fbi is no longer restarted by cron regularly but is triggered if a new image file has been downloaded and successfully processed by get_pics_by_mail.py. - updated README.me accordingly.
    [get_pics_by_mail.py]
2023-01-12 - fixed debug output.
    [blank_screen.py]
2023-01-13 - added off-hours. during this period, the screen ignores the motion sensor and stays off when blanked once.
2024-04-28 - Added code to support different motion sensors.
2024-05-04 - Added STLs and pictures of the redesign.
    [frame2_base.stl, frame2_case.stl, frame2_lower_bracket_pi_mount.stl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]
2024-05-04 - Forget to add a STL file.
    [frame2_passepartout_pin.stl]
2024-05-04 - Fixed the orientation of the STL files.
    [frame2_case.stl, frame2_lower_bracket_pi_mount.stl, frame2_passepartout.stl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]
2024-05-04 - Added assembly and 3d-printing instructions for the redesigned frame.
